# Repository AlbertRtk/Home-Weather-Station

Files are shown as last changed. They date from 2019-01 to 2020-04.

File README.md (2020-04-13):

# Home Weather Station

Arduino based DIY weather station which measures temperature, pressure and humidity in define time intervals and sends the data to Google Sheet. Later, the data can be read by an app on your computer or phone (in development).

## Weather station - main components
* Arduino Uno
* ESP-01 - Wi-Fi ESP8266 module
* BMP180
* DHT22 module
* Step-down power module or other source of 3.3 V to power ESP-01 (Arduino cannot handle it)

## Communication with ESP-01
* Connect ESP-01 and Arduino Uno as in the picture below to communicate with ESP-01 module through your Arduino board

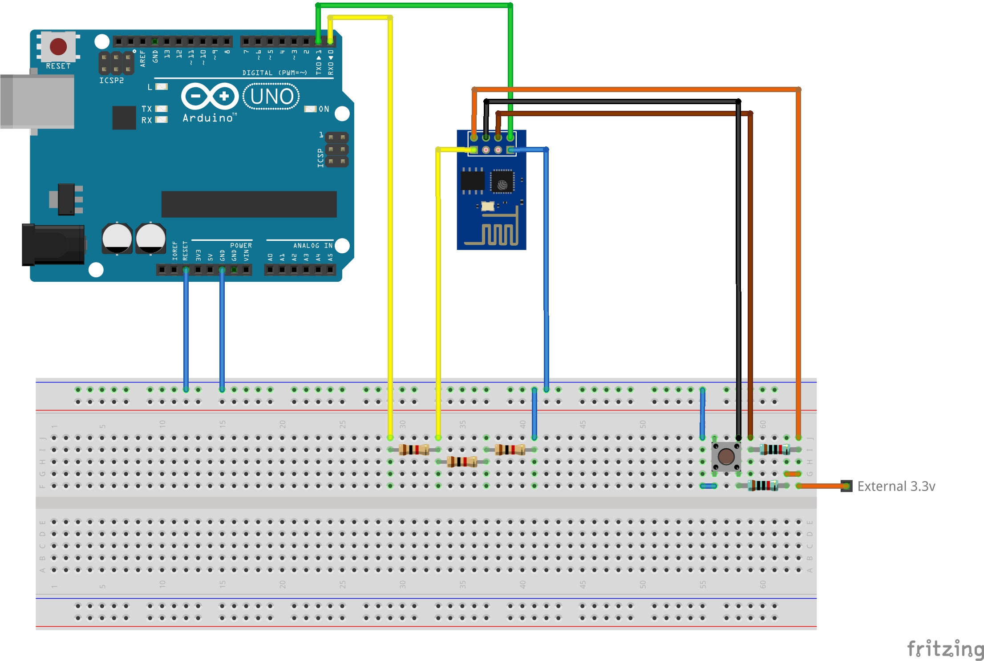
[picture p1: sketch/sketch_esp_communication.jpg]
Connection scheme


* Power ESP-01 and connect Arduino board via USB cable to your computer
* Run Arduino IDE and open Tools > Serial Monitor
* Choose "Both NL & CL" and Baud Rate 115200
* Type command `AT`. You should get `OK` response
* Change ESP-01 Baud Rate
```sh
AT+UART_DEF=9600,8,1,0,0
```
* Switch Serial Monitor to 9600 baud
* Set connection with your Wi-Fi. Connection will be saved in ESP8266 memory and set automatically after restart of the module
```sh
AT+CWMODE=3
AT+CWJAP="your wifi ssid","your wifi password"
```
* You can check if setting are saved by restarting the module. Connection to Wi-Fi should be established automatically now
```sh
AT+RST
```

## Weather station

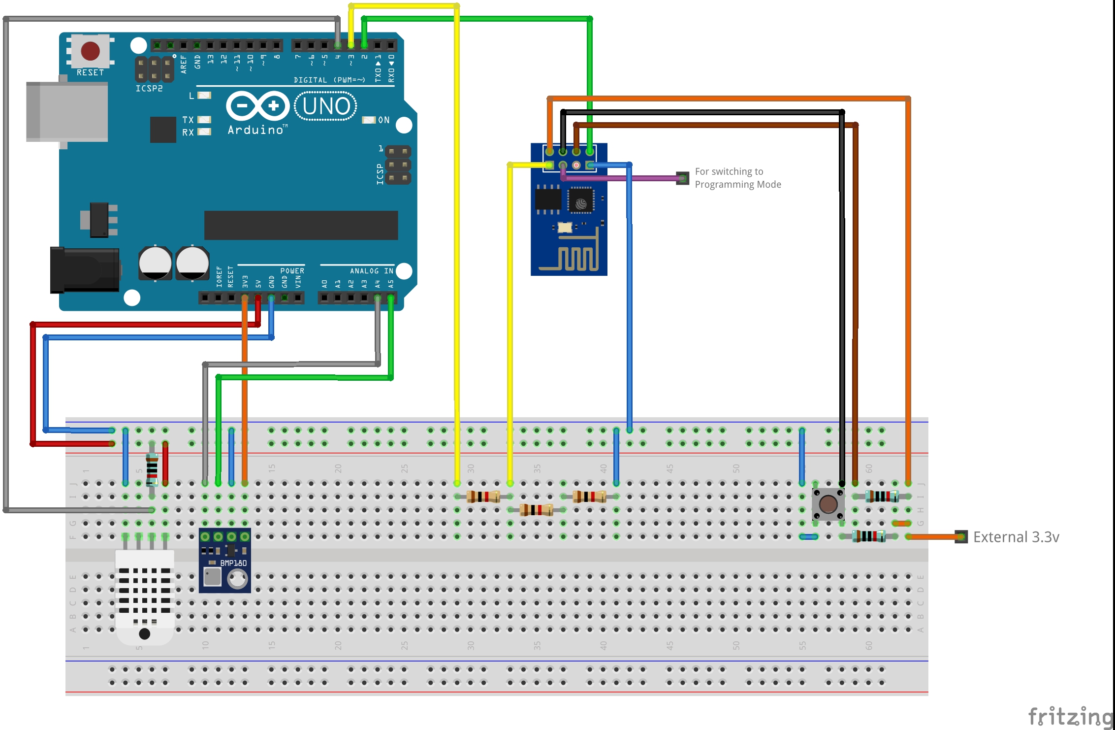
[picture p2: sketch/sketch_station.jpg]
Weather station scheme


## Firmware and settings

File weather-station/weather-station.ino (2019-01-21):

/* Arduino Weather Station
 * 2019, Albert Ratajczak
 */

// Print ESP8266 response for debuging
const boolean DEBUG = true;

#include <SoftwareSerial.h>
#include <Wire.h>
#include <SFE_BMP180.h>
#include "DHT.h"
#include "secret.h"    // file with my WiFi SSID and passward and Google Form ID

#define RX 2            // connected to ESP8266 TX pin
#define TX 3            // connected to ESP8266 RX pin
#define DHTTYPE DHT22   // DHT module number
#define DHTPIN 4        // pin for DHT22 signal

// Setting ESP8266, DHN22 and BMP180
SoftwareSerial esp(RX, TX); 
DHT dht(DHTPIN, DHTTYPE);
SFE_BMP180 bmp180;

// Host and port number for SSL connection
const String HOST = "docs.google.com";
const int PORT = 443;

// Maximal awaiting time for response from ESP8266
int rtime = 5000;  

// Variables for measurements of weather conditions
char state;
double temperature_bmp;
double pressure;
double temperature_dht;
double humidity;


void setup() {
  Serial.begin(9600);
  esp.begin(9600);
  while (!esp) {
    ;  // waiting for connection
  }
  sendToESP("AT+RST", rtime, "GOT IP");  // WiFi is saved in ESP8266
  bmp180.begin();
  dht.begin();
  delay(1000);
}


void loop() {    
  // Measureing temperature with BMP180
  bmp180.startTemperature();
  delay(500);
  bmp180.getTemperature(temperature_bmp);

  // Measuring pressure with BMP180
  state = bmp180.startPressure(3);
  delay(state);
  bmp180.getPressure(pressure, temperature_bmp);

  // Measuring humidity and temperature with DHT22
  humidity = dht.readHumidity();
  temperature_dht = dht.readTemperature();

  // Creating string with request to send to ESP8266
  // Help: https://tttapa.github.io/ESP8266/Chap09%20-%20Web%20Server.html
  String request = "GET /forms/d/e/" + FORM_ID + "/formResponse?" + 
                   "entry.1105778885=" + String(temperature_bmp) +
                   "&entry.1094475896=" + String(temperature_dht) + 
                   "&entry.896020747=" + String(pressure) +
                   "&entry.1330320364=" + String(humidity) +
                   "&submit=Submit HTTP/1.1\r\n" +
                   "Host: " + HOST + "\r\n" +
                   "Connection: close\r\n\r\n";

  // Setting SSL Buffer size - has to be large, 2048-4096
  sendToESP("AT+CIPSSLSIZE=4096", rtime, "OK");
  
  // Starting connection
  sendToESP("AT+CIPSTART=\"SSL\",\"" + HOST + "\"," + String(PORT), rtime, "OK");
  
  // Sending data to ESP8266 - setting the data length and passing request
  sendToESP("AT+CIPSEND="+String(request.length()+2), rtime, ">");
  sendToESP(request, rtime, "CLOSED");

  delay(900000);  // 15 min
}


boolean find(String string, String pattern){
  /* Checks if string contains pattern
   * Return: boolean, true or false
  */
  if(string.indexOf(pattern) >= 0)
    return true;
  return false;
}


void sendToESP(String command, const int timeout, String answer){
  /* Sends command to ESP8266 
   * Waits for timeout ms for response containing answer
   * Returns: String, response from ESP8266
  */
  char c;
  String message; 
  long int t = millis();
  
  if(DEBUG)
    Serial.println("\n\n>> ESP8266:"); 
    
  esp.println(command);
  
  while((t+timeout)>=millis()){ // while #1 - timeout
    while(esp.available()){     // while #2 - ESP8266 sends data
      c = esp.read();           // read byte
      message += c;             // compose response  
      if(DEBUG) 
        Serial.print(c); 
    }
    if(find(message, answer))
      break;  // break while-loop #1 if message contains answer
  }
}

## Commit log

2019-01-05 Correcting request and comments
    [weather_station.ino]
2019-01-16 Adding weather_station_app (prints values in terminal)
2019-01-20 Adding labels (T,H,p) and update button to the window
2019-01-20 Now SERVICE is build after pressing button - faster start
2019-01-27 Adding scetch
    [sketch_esp_communication.fzz, sketch_station.fzz]
